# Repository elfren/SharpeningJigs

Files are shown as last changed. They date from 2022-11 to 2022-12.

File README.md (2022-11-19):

# SharpeningJigs
These pucks are designed to be used manually on a flat diamond hone or knife sharpener as well as on lapping machines.  The carbide cutters are called split end or half straight.
The pucks and goniostats can be 3d printed with 30% infill.  The 3dPrintModifier may be used in slicer software to increase infill to 100% around the holes in the pucks.

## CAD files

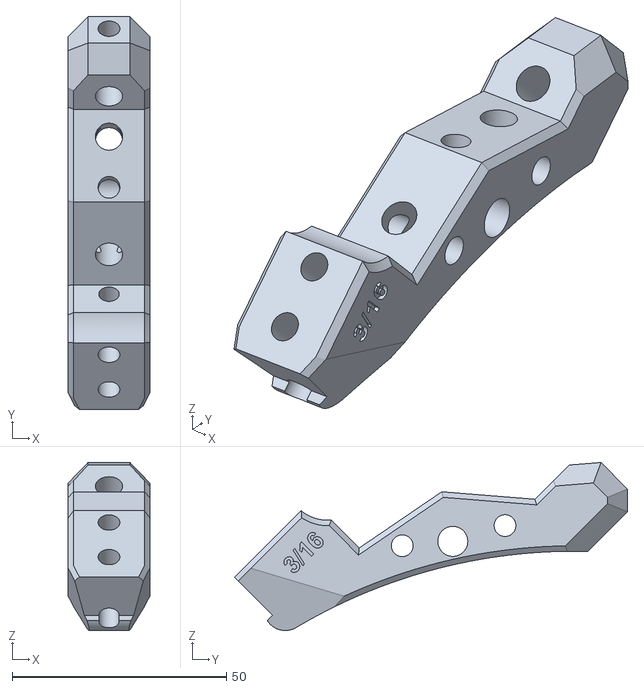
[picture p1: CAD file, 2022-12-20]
Goniostats/Goniostat_3-16.stl
19.0 x 91.7 x 39.2

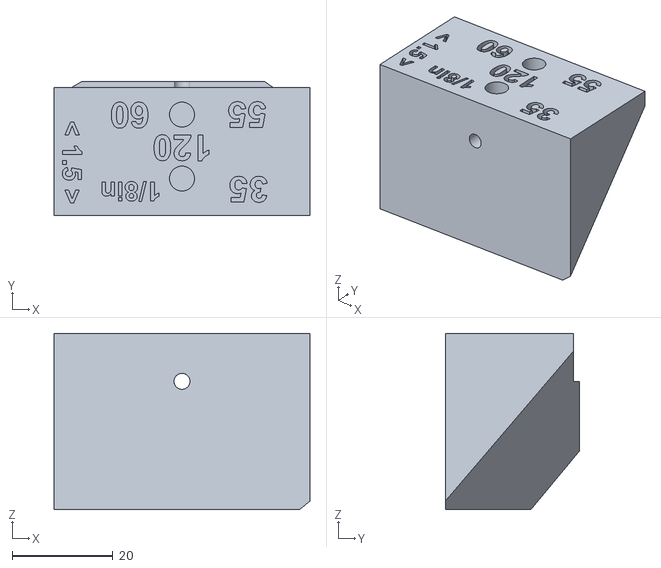
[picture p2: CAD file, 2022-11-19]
Pucks/Drill/1-8/Drill_Puck_120V_35R_1-8.stl
50.8 x 26.7 x 35.0

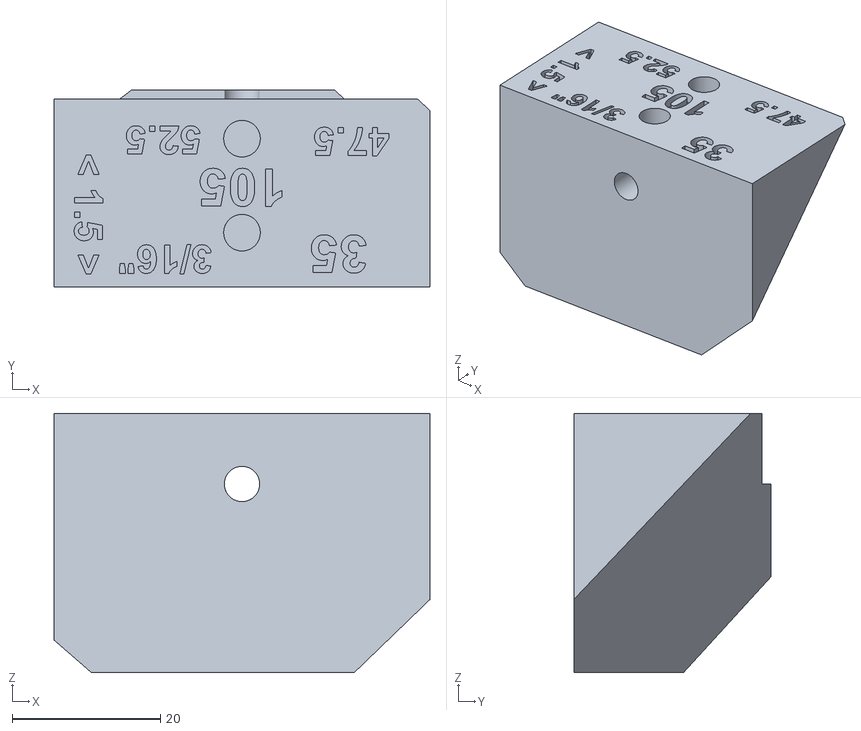
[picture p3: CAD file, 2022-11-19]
Pucks/Drill/3-16/Drill_Puck_105V_35R_3-16.stl
50.8 x 26.7 x 35.0

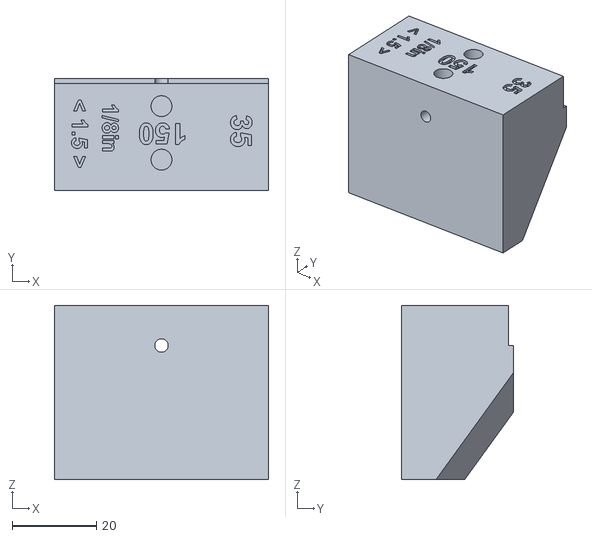
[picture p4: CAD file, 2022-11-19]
Pucks/FlyCutter/1-8/FlyCutter_Puck_150V_35R_1-8.stl
50.8 x 26.7 x 41.3

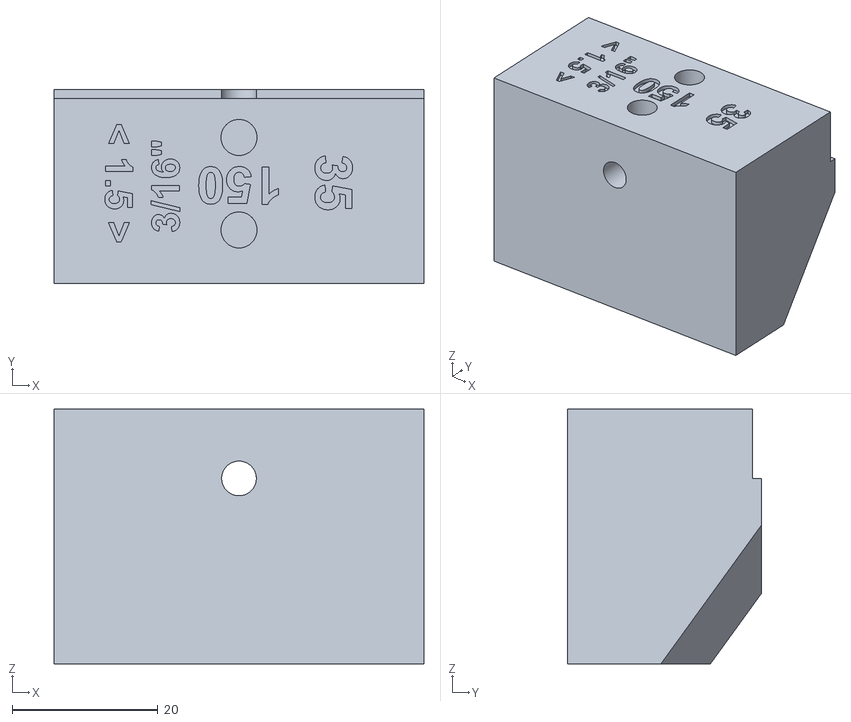
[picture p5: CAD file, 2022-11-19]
Pucks/FlyCutter/3-16/FlyCutter_Puck_150V_35R_3-16.stl
50.8 x 26.7 x 35.0

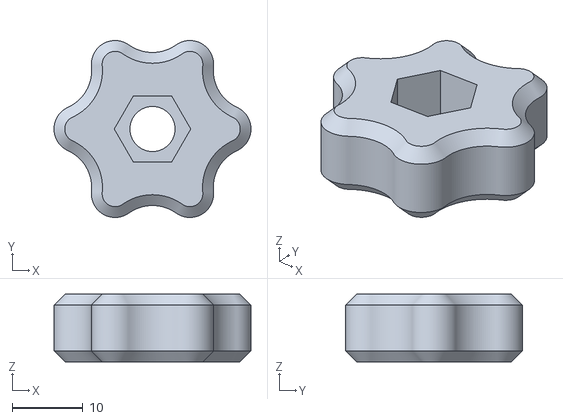
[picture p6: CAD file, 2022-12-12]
Pucks/Knobs_6Lobe.stl
27.8 x 25.0 x 9.52

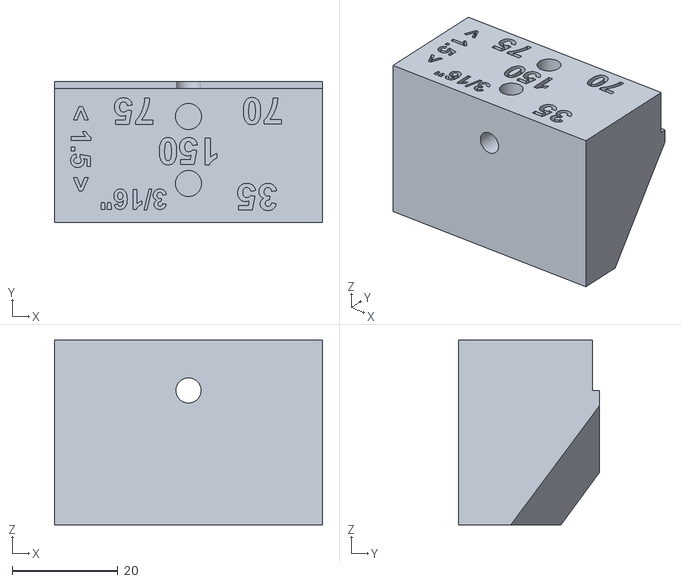
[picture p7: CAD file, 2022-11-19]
Pucks/Drill/3-16/Drill_Puck_150V_35R_3-16.stl
50.8 x 26.7 x 35.0

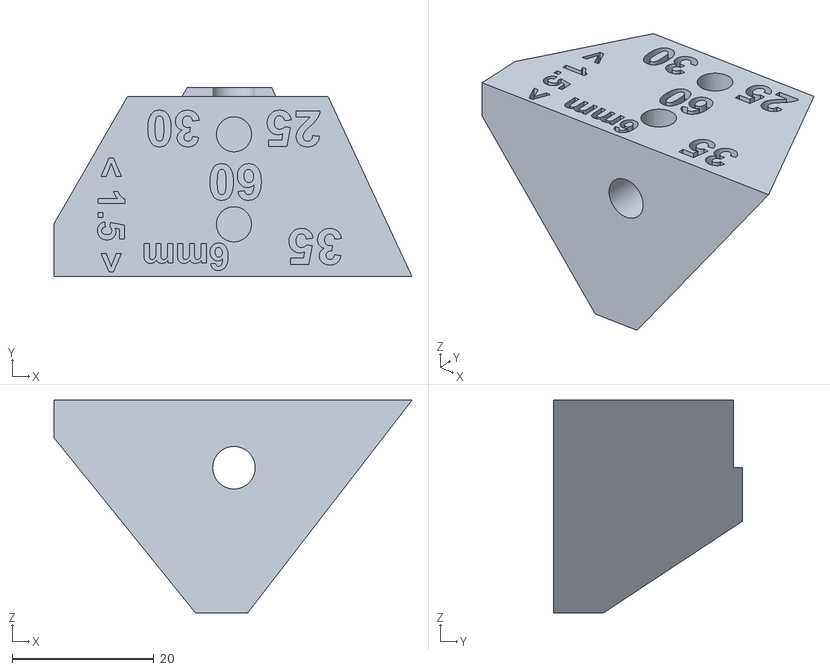
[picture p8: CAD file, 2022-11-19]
Pucks/Drill/6mm/Drill_Puck_60V_35R_6mm.stl
50.5 x 26.7 x 30.0

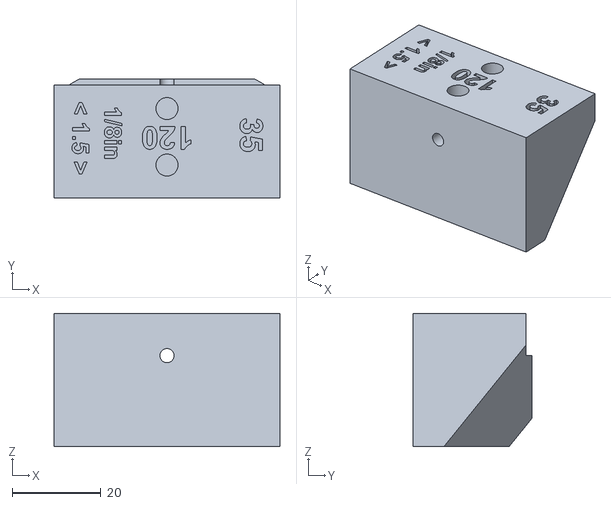
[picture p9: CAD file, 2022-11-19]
Pucks/FlyCutter/1-8/FlyCutter_Puck_120V_35R_1-8.stl
50.8 x 26.7 x 30.0

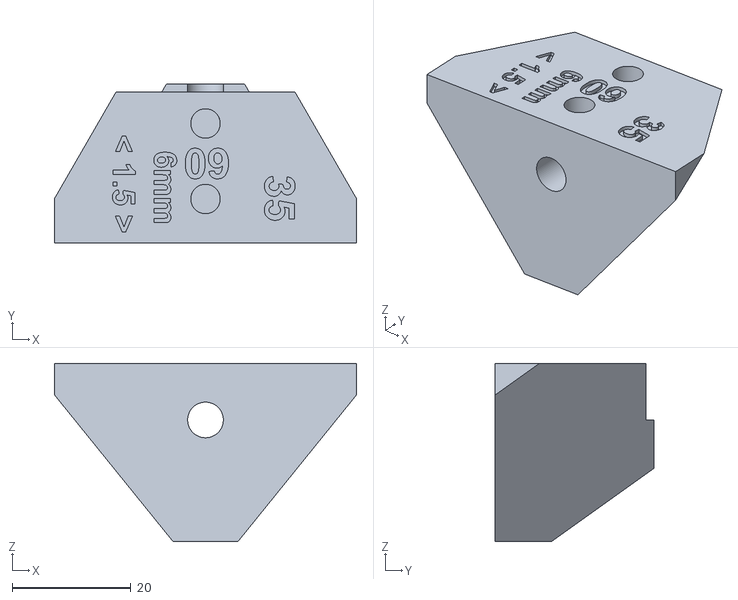
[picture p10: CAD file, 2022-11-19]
Pucks/FlyCutter/6mm/FlyCutter_Puck_60V_35R_6mm.stl
50.8 x 26.7 x 30.0

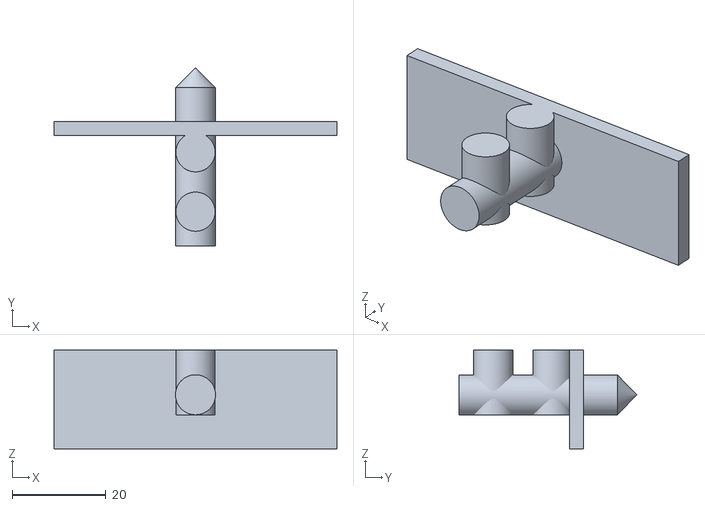
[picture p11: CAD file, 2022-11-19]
Pucks/Puck_3dPrintModifier.stl
60.5 x 38.1 x 21.1

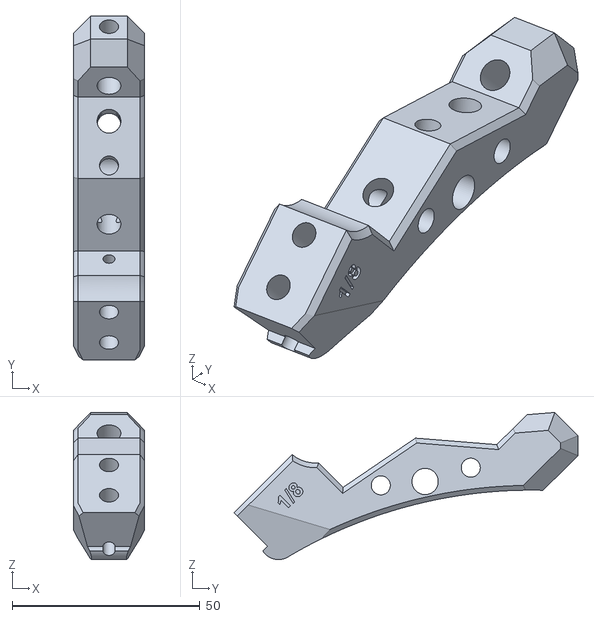
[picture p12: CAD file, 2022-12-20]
Goniostats/Goniostat_1-8.stl
19.0 x 91.7 x 39.2

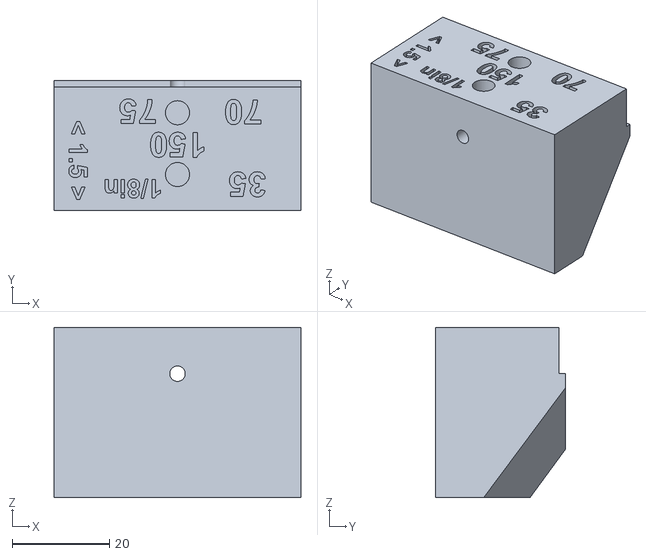
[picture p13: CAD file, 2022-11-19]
Pucks/Drill/1-8/Drill_Puck_150V_35R_1-8.stl
50.8 x 26.7 x 35.0

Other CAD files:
Pucks/Drill/6mm/Drill_Puck_120V_35R_6mm.stl
Pucks/FlyCutter/6mm/FlyCutter_Puck_150V_35R_6mm.stl
Goniostats/Goniostat_6mm.stl
Pucks/Drill/1-8/Drill_Puck_105V_35R_1-8.stl
Pucks/FlyCutter/3-16/FlyCutter_Puck_120V_35R_3-16.stl
Goniostats/Goniostat_6mm.f3d
Pucks/Drill/1-8/Drill_Puck_135V_35R_1-8.stl
Pucks/Drill/1-8/Drill_Puck_60V_35R_1-8.stl
Pucks/Drill/1-8/Drill_Puck_75V_35R_1-8.stl
Pucks/Drill/1-8/Drill_Puck_90V_35R_1-8.stl
Pucks/Drill/3-16/Drill_Puck_120V_35R_3-16.stl
Pucks/Drill/3-16/Drill_Puck_135V_35R_3-16.stl
Pucks/Drill/3-16/Drill_Puck_60V_35R_3-16.stl
Pucks/Drill/3-16/Drill_Puck_75V_35R_3-16.stl
Pucks/Drill/3-16/Drill_Puck_90V_35R_3-16.stl
Pucks/Drill/6mm/Drill_Puck_105V_35R_6mm.stl
Pucks/Drill/6mm/Drill_Puck_135V_35R_6mm.stl
Pucks/Drill/6mm/Drill_Puck_150V_35R_6mm.stl
Pucks/Drill/6mm/Drill_Puck_75V_35R_6mm.stl
Pucks/Drill/6mm/Drill_Puck_90V_35R_6mm.stl
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

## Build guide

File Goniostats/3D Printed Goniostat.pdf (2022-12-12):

# 3D Printed Goniostat

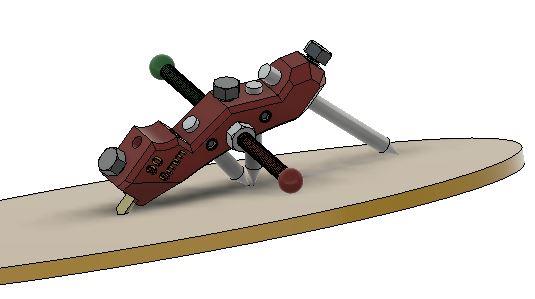
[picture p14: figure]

There are three models, one for each cutter size: 6mm, 3/16”, and 1/8”.

Print the models with four to five perimeters to allow solid material for the threads. 30% infill will make a very strong body, but anything from 10% to 100% should work fine. Print with side down, supports may be needed.

All of the locking screws are ¼”-20. Nylon set screws work best on the sides, on the top, any style is fine.

Reaming the arm and cutter holes will give the most accurate results.

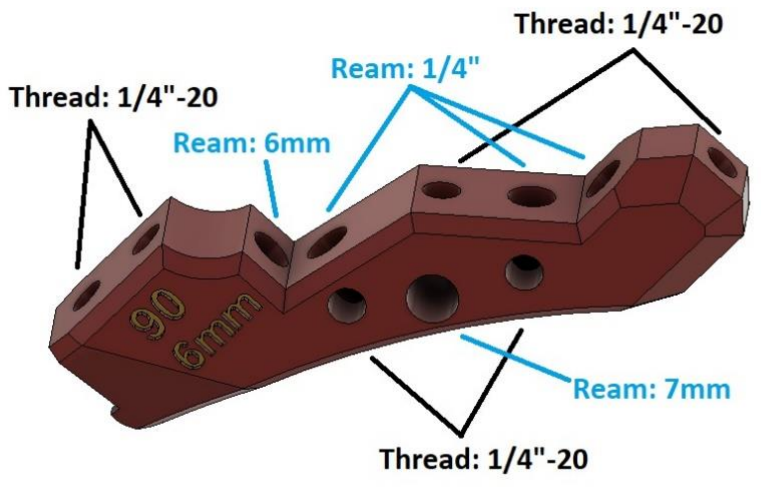
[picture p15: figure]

Horizontal arm construction:

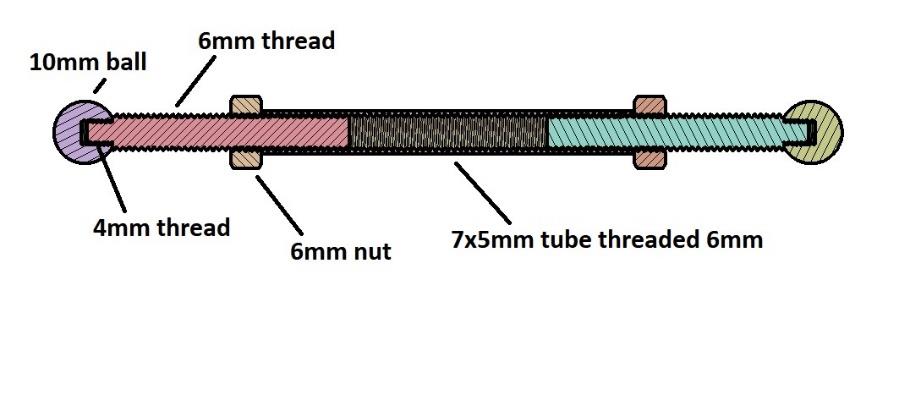
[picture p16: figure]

Horizontal arm length and cutter stick out table:

Tip
Angle | CutterStickOut ArmMeasureLength
60 | 0.5 | 1.125
75 | 0.5 | 1.315
90 | 0.5 | 1.705
105 | 0.375 | 2.035
120 | 0.375 | 2.645
135 | 0.375 | 3.575
150 | 0.375 | 5.335

Cutter stick out is measured from the front upper vertical surface in inches. Horizontal arms are measured from the opposite side of the body to the tip of the arm. The goniostat body is .75” wide. The horizontal arms can also be made full length from bar stock.

Vertical arms:

The rear arm determines the side relief angle. The center arms determine the maximum finished length of the cutter. Only one center arm is used depending on whether or not an arm hole is blocked by another arm or the cutter. The rearmost center arm is preferable.

Arms are ¼” diameter. Tip can be pointed or a ball. The radius of the tip determines the radius of the cutter tip.

Locking knob:

3d print knob, (https://github.com/elfren/SharpeningJigs/blob/main/Goniostats/Knobs_6Lobe.stl) then press ¼” nylon hex bolt into it. Use to lock the cutter in place.

Resources:

Models: https://github.com/elfren/SharpeningJigs/tree/main/Goniostats

Balls: https://www.amazon.com/dp/B09P9SPRF6?psc=1&ref=ppx_yo2ov_dt_b_product_details

6mm threaded rod:
https://www.amazon.com/dp/B08FR4G12H?psc=1&ref=ppx_yo2ov_dt_b_product_details

7x5mm tube:
https://www.amazon.com/dp/B07Z98KQWR?psc=1&ref=ppx_yo2ov_dt_b_product_details

¼” rod: https://www.amazon.com/dp/B0B8NTBDP8?psc=1&ref=ppx_yo2ov_dt_b_product_details

Nylon set screw:
https://www.amazon.com/dp/B07HJGQ1TR?psc=1&ref=ppx_yo2ov_dt_b_product_details

Nylon hex bolt: https://www.mcmaster.com/99091A539/

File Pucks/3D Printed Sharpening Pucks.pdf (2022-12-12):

# 3D Printed Sharpening Jigs

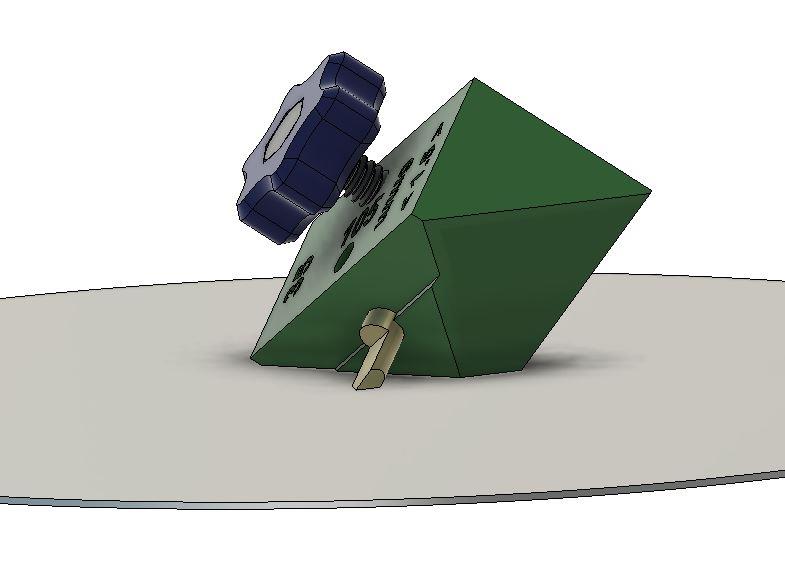
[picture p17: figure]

These jigs are primarily used to hand sharpen engraving style bits on diamond lapping plates. There are two styles. The flycutter style tip has equal angles on both sides, while the drill style tips’ right side angle is 5 degrees less than the left side. The flycutter style is used in universal, horizontal, and vertical cutting frames, while the drill style is used in a drilling frame.

Printing and preparing the jigs:

Print with the back side down, three or more perimeters, and 30% infill. Cubic or Gyroid are the strongest infill options. Use the model, Puck_3dPrintModifier.stl, as a 100% infill modifier.

The two top holes need to be tapped ¼”x20. The cutter hole may need to be reamed or drilled to size depending on how well your printer is calibrated.

You may need to flatten the angled sides with a sanding block as some printers may make the borders slightly higher than the center.

Sizes:

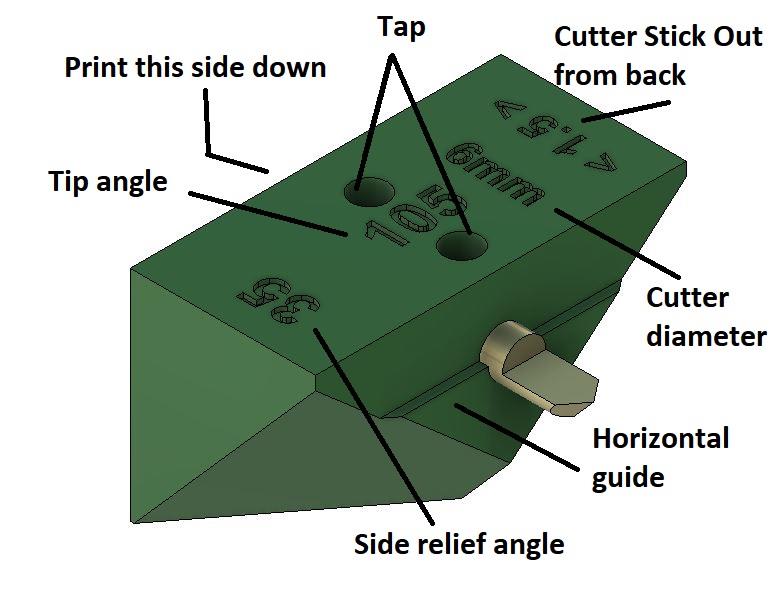
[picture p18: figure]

Tip angles from 60 degrees to 150 degrees in 15 degree increments in each of these cutter diameters: 1/8”, 3/16”, and 6mm. All jigs have 35 degree side relief angle.

Usage:

Insert the cutter blank so the sharpened tip will be 1.5 inches from the back or .5 inches from the upper front face. The cutter should be level with the horizontal guide.

150 grit diamond lap works well for initial shaping. 600, 1200, 2000, and 3000 grit laps are used in order for a mirror finish.

Most carbide engraving bits have a large relief on the right hand side, so care must be taken to get the tip on the center line. This is critical for the drilling frame bits. Fly cutters can be adjusted for center height.

Locking knob:

3d print knob, (https://github.com/elfren/SharpeningJigs/blob/main/Pucks/Knobs_6Lobe.stl) then press ¼” nylon hex bolt into it. Use to lock the cutter in place.

Resources:

Models: https://github.com/elfren/SharpeningJigs/tree/main/Pucks

Engraving bits, these are just examples. There are many more available.

6mm*15mm, Half straight bit – aliexpress item 2251801868877245

3.175*3.0*8mm Straight Milling Cutter – aliexpress item 2251832423982437

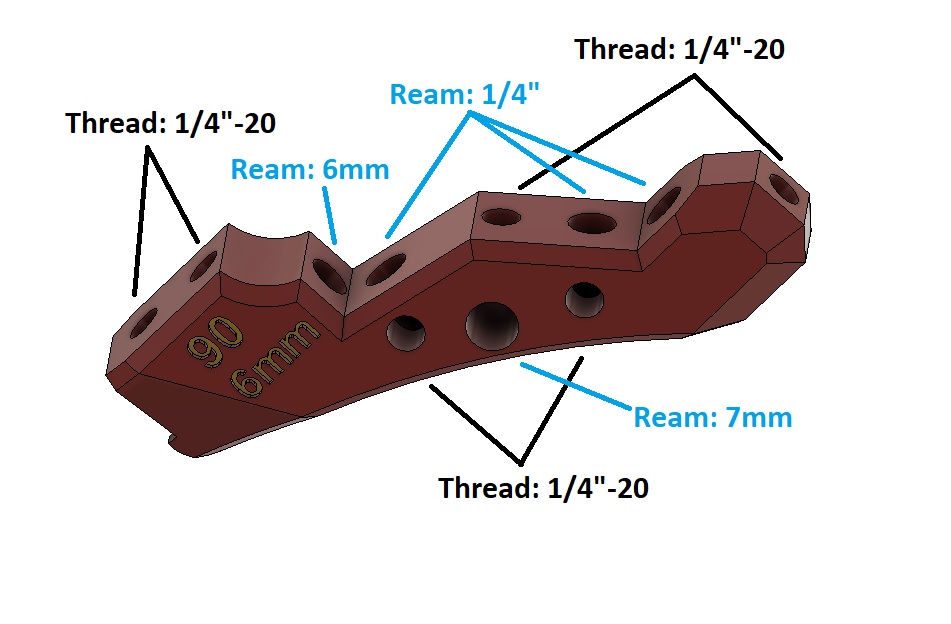
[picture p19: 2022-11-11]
Goniostats/ThreadAndReamGuide.jpg
